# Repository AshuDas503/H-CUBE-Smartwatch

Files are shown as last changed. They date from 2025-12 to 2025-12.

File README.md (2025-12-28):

# H-CUBE-Smartwatch
A custom retro-style smartwatch powered by ESP32-S3 and HCMS-2971 LED display. Open-source hardware and firmware.

# H-CUBE: Retro-Style ESP32-S3 Smartwatch






**H-CUBE** ("Hardware Cube") is a fully custom, open-source smartwatch project that blends 80s retro aesthetics with modern IoT capabilities. Powered by the **ESP32-S3** and featuring a vintage **HCMS-2971** alphanumeric LED display, this wearable serves as a compact development platform for embedded systems, integrating GPS, motion sensing, and power management into a 3D-printed enclosure.

---

## 📸 Gallery

<!-- Upload images to an 'images' folder in your repo and uncomment the lines below -->
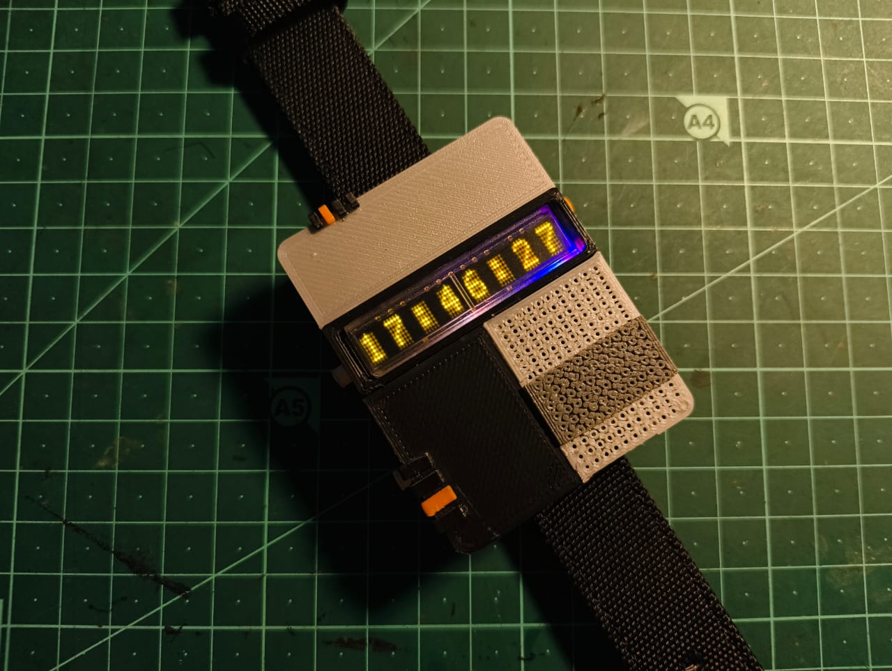
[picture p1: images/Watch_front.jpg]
H-CUBE Front View

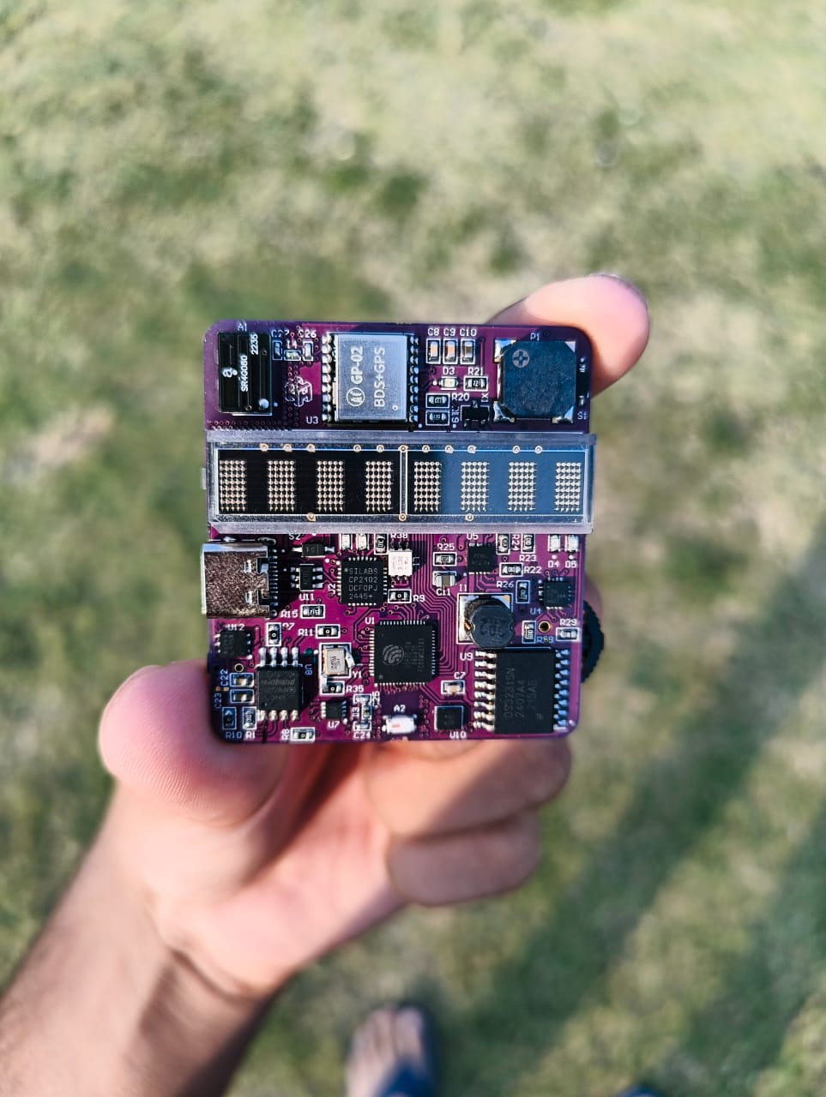
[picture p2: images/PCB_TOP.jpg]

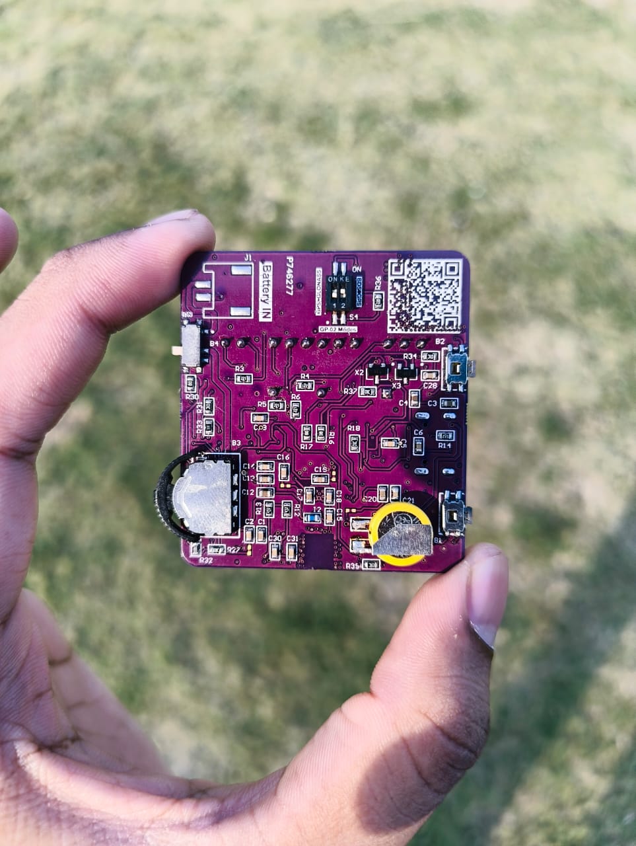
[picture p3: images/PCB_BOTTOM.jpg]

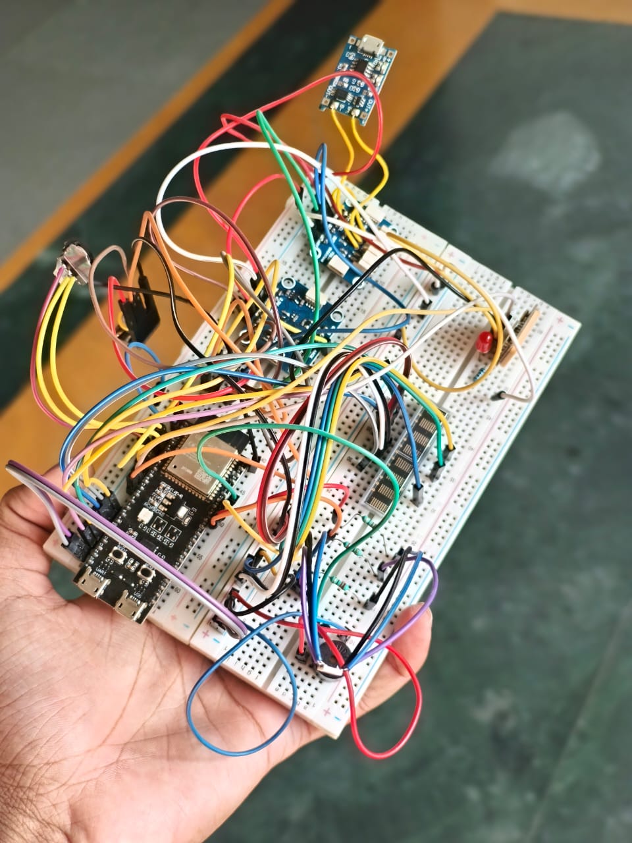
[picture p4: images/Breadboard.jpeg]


---

## 🚀 Features

### Hardware
*   **Core:** ESP32-S3 (Dual-core 240 MHz, WiFi + BLE 5.0).
*   **Display:** HCMS-2971 8-Character Yellow Alphanumeric LED (Vintage aesthetic, ~2000 nits brightness).
*   **Sensors:**
    *   **IMU:** BMI270 (6-axis accelerometer/gyroscope) for motion detection and wake-on-raise.
    *   **GPS:** GP-02 GNSS module for location tracking and time sync.
    *   **RTC:** DS3231 Precision Real-Time Clock for accurate timekeeping during sleep.
*   **Power:**
    *   **Charger:** BQ24075 with power path management.
    *   **Fuel Gauge:** MAX17048 for precise battery percentage monitoring.
    *   **Runtime:** 8-12 hours active use, with intelligent deep-sleep (10s timeout).
*   **User Interface:** 3-way navigation switch, RGB LED indicators, and Piezo Buzzer.

### Firmware & Software
*   **12 Operational Modes:** Time, Date, GPS Info, Temperature, Alarm, Stopwatch, Timer, RGB Control, Battery Status, Settings, etc.
*   **Connectivity:** Bluetooth SPP (Serial Port Profile) for phone pairing and WiFi for NTP time sync.
*   **OTA Updates:** Supports Over-The-Air firmware flashing.
*   **Power Saving:** Optimized sleep routines using the ESP32 ULP (Ultra Low Power) co-processor features.

---

## 🛠️ Tech Stack & Tools

*   **PCB Design:** Altium Designer (4-Layer Stackup, Impedance Controlled).
*   **CAD/Enclosure:** Autodesk Fusion 360 (Housing), KeyShot/Rhino (Rendering).
*   **Firmware:** C/C++ (Arduino IDE / PlatformIO).
*   **Fabrication:** 3D Printing (SLA/FDM for enclosure), Hot-plate Reflow (SMD Assembly).

---

## ⚡ Getting Started

### 1. Prerequisites
*   **Hardware:** H-CUBE PCB (assembled), LiPo Battery (3.7V), FTDI programmer (if not using USB-native boot).
*   **Software:** Arduino IDE (v2.0+) or PlatformIO.

### 2. Firmware Installation
1.  Clone this repository:
    ```
    git clone https://github.com/AshuDas503/H-CUBE.git
    ```
2.  Open the project in **Arduino IDE**.
3.  Install required libraries via Library Manager:
    *   `Adafruit_NeoPixel`
    *   `RTClib` (Adafruit)
    *   `SparkFun_BMI270_Arduino_Library`
    *   `TinyGPSPlus`
    *   *Note: Check `firmware/library_list.txt` for specific versions.*
4.  Select Board: **ESP32S3 Dev Module**.
    *   *USB CDC On Boot:* Enabled
    *   *Flash Size:* 8MB (or matches your specific IC)
5.  Connect the H-CUBE via USB and click **Upload**.

### 3. Assembly
*   Refer to the `Enclosure/README.md` for 3D printing settings (Layer height: 0.12mm recommended).
*   Wiring diagrams and pinout maps can be found in `Hardware/schematics/`.

---

## 🎮 Controls

*   **Center Click:** Wake / Enter Menu / Select.
*   **Up/Down:** Navigation / Value Adjustment.
*   **Long Press (Center):** Power Off / Sleep.

---

## 🤝 Contributing

Contributions are welcome!
1.  Fork the Project
2.  Create your Feature Branch (`git checkout -b feature/AmazingFeature`)
3.  Commit your Changes (`git commit -m 'Add some AmazingFeature'`)
4.  Push to the Branch (`git push origin feature/AmazingFeature`)
5.  Open a Pull Request

---

## 📜 License

This project is licensed under the MIT License - see the [LICENSE](LICENSE) file for details.

---

## 🔗 References & Links

*   **Instructables Guide:** [https://www.instructables.com/H-CUBE-a-Retro-Style-Smart-Watch-Powered-by-an-ESP/]
*   **Video Demo:** [https://www.youtube.com/watch?v=HaJIaakPBnE&t=3s]

---

*Created by **Ashutosh Dash**.*

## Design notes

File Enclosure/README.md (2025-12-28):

# 3D Printing Instructions

## Settings
*   **Material:** PLA or PETG
*   **Layer Height:** 0.12mm (for fine detail on the buttons)
*   **Infill:** 100% (for durability)
*   **Supports:** Required for the button cutouts.

## Assembly
1.  Sand the button slots slightly.
2.  Insert the 3D printed buttons.
3.  Place the PCB...

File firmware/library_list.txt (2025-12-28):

H-CUBE FIRMWARE - REQUIRED LIBRARIES
====================================

Library Name                          | Version   | Purpose
--------------------------------------|-----------|----------------------------
Adafruit_NeoPixel                     | 1.10.7    | RGB LED control
RTClib (Adafruit)                     | 2.1.1     | DS3231 Real-Time Clock
SparkFun_BMI270_Arduino_Library       | 1.0.8     | BMI270 IMU sensor
TinyGPSPlus                           | 1.0.3     | GP-02 GPS parsing
LedDisplay (Stoffregen)               | 0.4.1     | HCMS-2971 alphanumeric LED display
Preferences                           | N/A       | Built-in ESP32 (no install needed)
Wire                                  | N/A       | Built-in I2C library
SPI                                   | N/A       | Built-in SPI library
WiFi                                  | N/A       | Built-in WiFi (ESP32)
BluetoothSerial                       | N/A       | Built-in Bluetooth (ESP32)

INSTALLATION INSTRUCTIONS:
==========================

1. Open Arduino IDE
2. Go to: Sketch > Include Library > Manage Libraries
3. Search for each library name above
4. Install the version listed
5. Restart Arduino IDE

For GitHub Installation (LedDisplay):
If not available in Library Manager, install manually:
1. Download: https://github.com/PaulStoffregen/LedDisplay
2. Extract to: ~/Documents/Arduino/libraries/
3. Restart Arduino IDE

For PlatformIO users:
Add to platformio.ini:
lib_deps =
    adafruit/Adafruit NeoPixel @ 1.10.7
    adafruit/RTClib @ 2.1.1
    sparkfun/SparkFun BMI270 Arduino Library @ 1.0.8
    mikalhart/TinyGPSPlus @ 1.0.3
    https://github.com/PaulStoffregen/LedDisplay.git

NOTES:
======
- If a library version is marked as "Built-in", you don't need to install it.
- Always use the versions listed above for compatibility.
- If you get compilation errors, check that all libraries are installed.

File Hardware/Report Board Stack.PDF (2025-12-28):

# Board Stack Report

Stack Up | Layer Stack
Layer | Board Layer Stack | Name | Material | Thickness | Constant | Dk | Df | Coverlay expansion | Color | Frequency | Solid | GlassTransTemp | Manufacturer | MaterialDescription | Description | Process | Orientation | Copper Orientation | Weight | Constructions | Resin | Pullback distance
1 | | Top Overlay | | 0mm
2 | | Top Solder | SM-001 | 0.0254mm | 4 | 4 | 0.03 | 0mm | #FF008000 | 1GHz | 1% | 125°C | Altium Designer | Solder Mask | Solder Mask
3 | | Top Surface Finish | Nickel, Gold | 0.004mm | | | | | #FFFFC400 | | | | | | | ENIG
4 | | SIG L1 | CF-004 | 0.035mm | | | | | | | | | Altium Designer | Copper Foil | Copper Foil | ED | BodyUp | Above | 28.34952g
5 | | PP1-2116 | PP-017 | 0.105mm | 4.3 | 4.3 | 0.02 | | | 1GHz | | 180°C | Altium Designer | | | | | | | 2116 | 57%
6 | | SIG L2 | CF-004 | 0.035mm | | | | | | | | | Altium Designer | Copper Foil | Copper Foil | ED | None | Above | 28.34952g | | | 0.508mm
7 | | Core-FR4 | Core-039 | 1.2mm | 4.8 | 4.8 | 0.02 | | | 1GHz | | 180°C | Altium Designer | FR4 | | | | | | 4-7628 | 40%
8 | | SIG L3 | CF-004 | 0.035mm | | | | | | | | | Altium Designer | Copper Foil | Copper Foil | ED | None | Below | 28.34952g | | | 0.508mm
9 | | PP2-2116 | PP-017 | 0.105mm | 4.3 | 4.3 | 0.02 | | | 1GHz | | 180°C | Altium Designer | | | | | | | 2116 | 57%
10 | | SIG L4 | CF-004 | 0.035mm | | | | | | | | | Altium Designer | Copper Foil | Copper Foil | ED | BodyDown | Below | 28.34952g
11 | | Bottom Surface Finish | Nickel, Gold | 0.004mm | | | | | #FFFFC400 | | | | | | | ENIG
12 | | Bottom Solder | SM-001 | 0.0254mm | 4 | 4 | 0.03 | 0mm | #FF008000 | 1GHz | 1% | 125°C | Altium Designer | Solder Mask | Solder Mask
13 | | Bottom Overlay | | 0mm
| Height : 1.60881mm

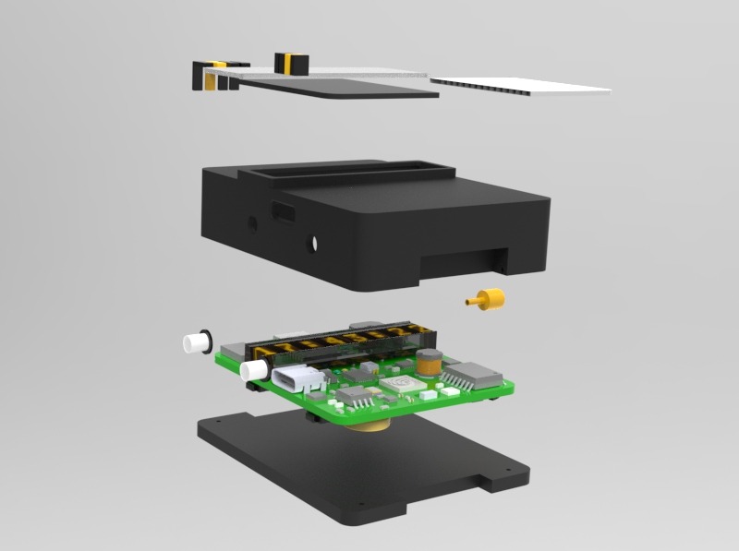
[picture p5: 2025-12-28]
images/Render 2.jpg

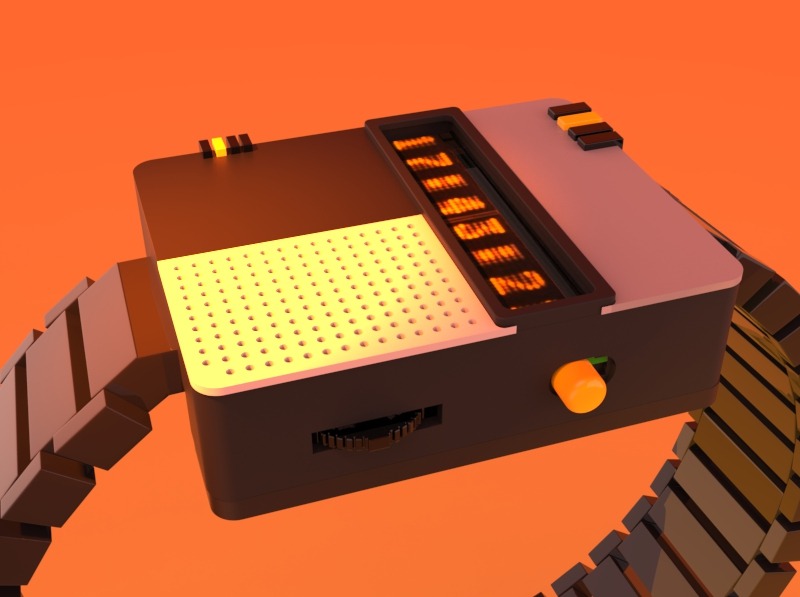
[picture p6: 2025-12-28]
images/Render 3.jpg

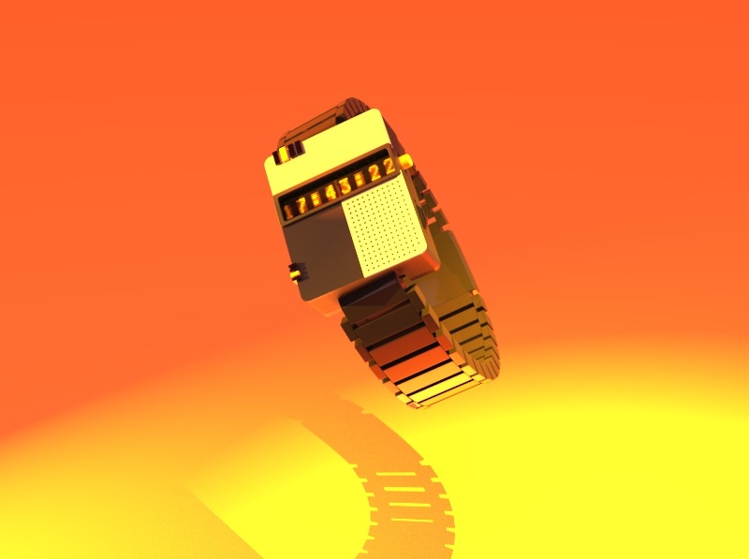
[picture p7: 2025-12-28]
images/Render 1.jpg

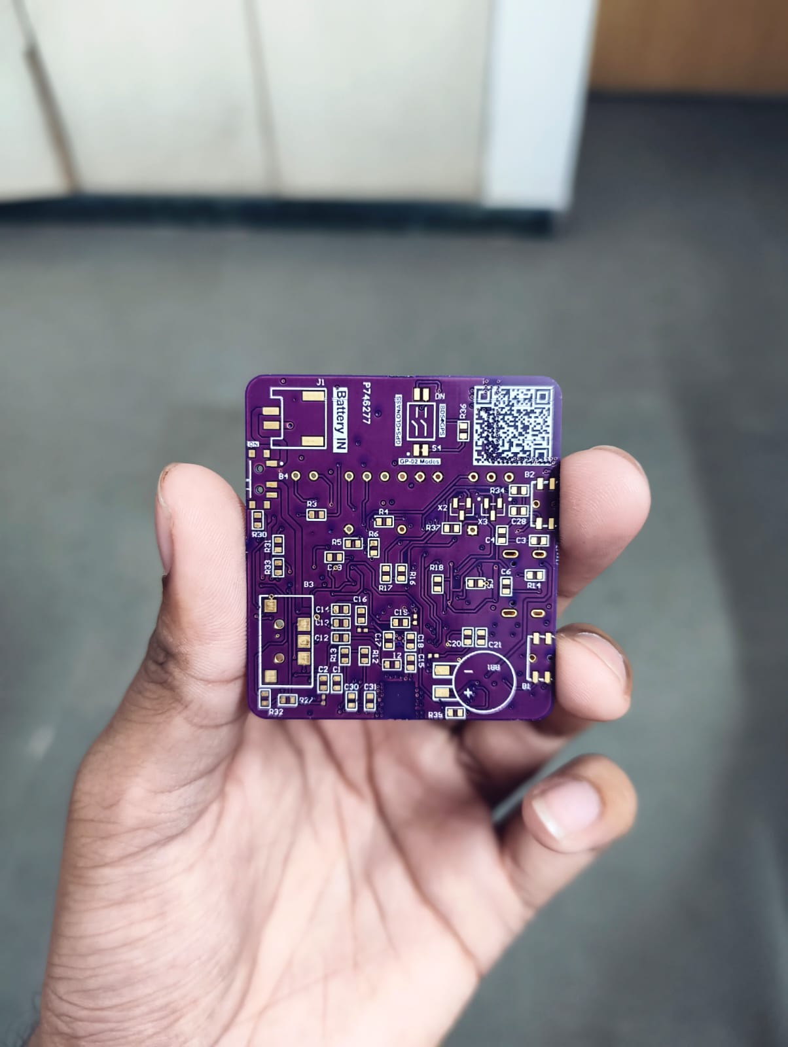
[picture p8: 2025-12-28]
images/PCB View1.jpg

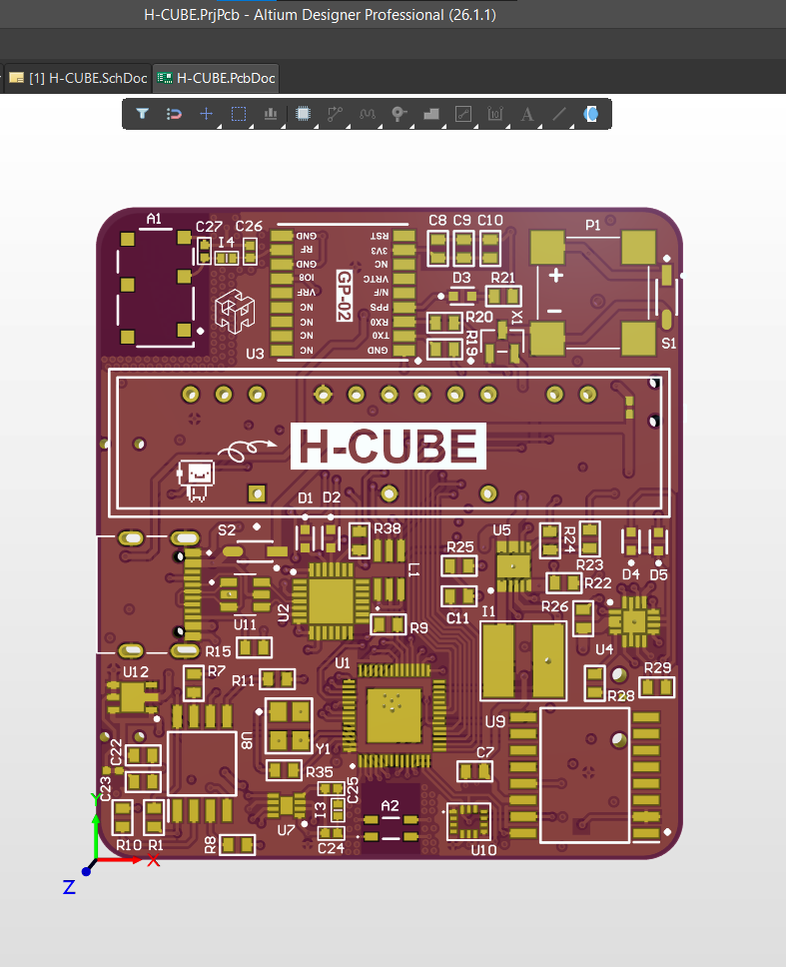
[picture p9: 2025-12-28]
images/3D TOP.png

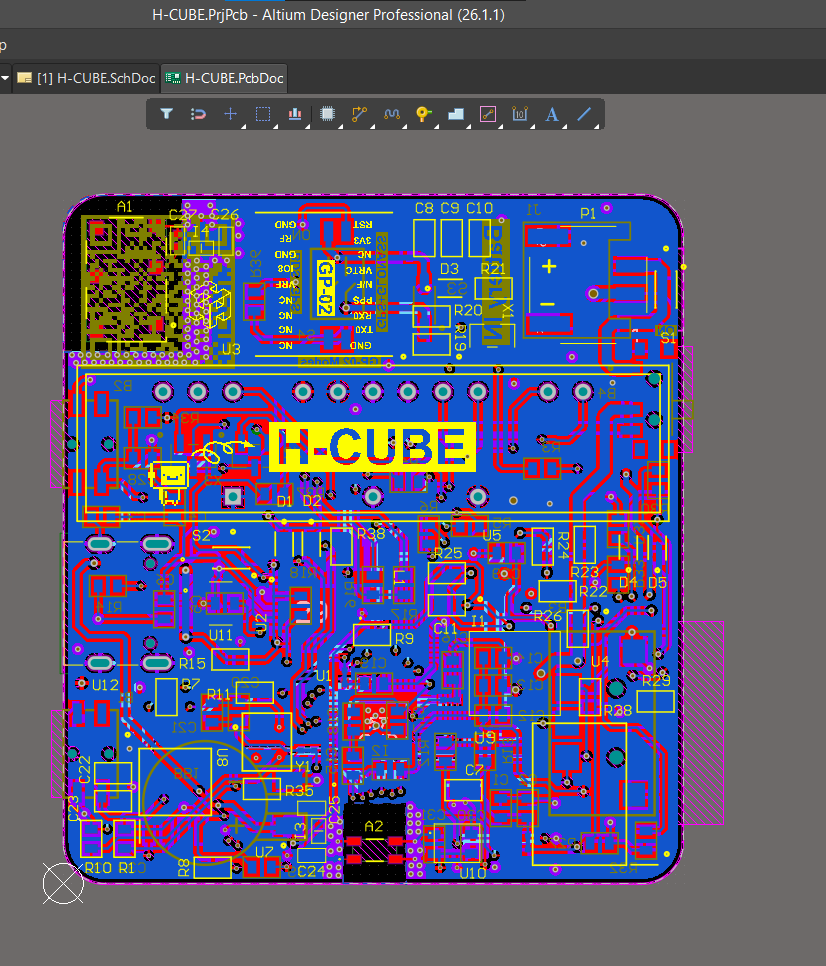
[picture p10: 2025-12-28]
images/Layer 4.png

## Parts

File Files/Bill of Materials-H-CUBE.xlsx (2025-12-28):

Line # | Name | Description | Designator | Quantity | Manufacturer 1 | Manufacturer Part Number 1 | Manufacturer Lifecycle 1 | Supplier 1 | Supplier Part Number 1 | Supplier Unit Price 1 | Supplier Subtotal 1
 | SR4G080 | GNSS Antenna chip type | A1 | 1
 | 2450AT18D0100001E | 2.4GHz Chip RF Antenna 2.4GHz ~ 2.5GHz 1.5dBi Solder Surface Mount | A2 | 1
 | BOOT |  | B1 | 1
 | RST |  | B2 | 1
 | LS-1305 | 3 way navigation switch Spring return, center push, Single knob can move CW/CCW/PUSH Specification:- Rating 10mA.5V DC Contact resitance 100MΩ max. Operating temperature range -30°C to +85°C Lifetime 100,000 Cycles min Operating force Lever portion 120±30gf / Push portion205±50gf Travel 3-direction-25°-0°~+25° / push portion 0.90±0.1mm | B3 | 1
 | CUS-12TB |  | B4 | 1
 | Battery |  | BB1 | 1
 | 1uf | 0603 ceramic capacitor | C1 | 1
 | 100nf | 0603 ceramic capacitor | C2, C14, C15, C16, C18, C19, C29, C30, C31 | 9
 | 1uF | 0603 ceramic capacitor | C3, C13, C17, C20, C22, C23 | 6
 | 10uF | 0603 ceramic capacitor | C4, C10, C12 | 3
 | 100nF | 0603 ceramic capacitor | C5, C6, C7, C8, C28 | 5
 | 820pF | 0603 ceramic capacitor | C9 | 1
 | 22uF | 0603 ceramic capacitor | C11 | 1
 | 10nF | 0603 ceramic capacitor | C21 | 1
 | 2.4pF | 0402 | C24 | 1
 | 2.7pF | 0402 | C25 | 1
 | 4.3pF | 0402 | C26 | 1
 | 3.6pF | 0402 | C27 | 1
 | 0603 G |  | D1 | 1
 | 0603 Y |  | D2 | 1
 | 0603 B |  | D3, D4 | 2
 | 0603 R |  | D5 | 1
 | HCMS-2971 | LED Displays & Accessories Yelow 585nm 1x8 Alphanumeric | H1 | 1
 | CD54-uH | Fixed Inductors SMD Power Inductor Unshielded | I1 | 1
 | 2nH | RF Inductors - SMD WE-KI 0603 2nH 700mA 80mOhms 0.2nH AEC-Q200 | I2 | 1
 | 2.4nH |  | I3 | 1
 | 5.1nH |  | I4 | 1
 | JST 2MM 2 |  | J1 | 1
 | ASMT-YTD2-0BB02 |  | L1 | 1
 | NT |  | NT1, NT2, NT3, NT4, NT5, NT6, NT7 | 7
 | MLT-8530 | PCB Mount type, SMD, External Drive, Magnetic 2700Hz 80dB Size Square 8.5x8.5x3mm, Low Profile, Sound output on side. | P1 | 1
 | 100k |  | R1, R22, R23, R26 | 4
 | 220R |  | R3, R4, R5, R6, R21 | 5
 | 0R |  | R7, R8, R9, R10, R11, R35 | 6
 | 4K7 |  | R12, R13 | 2
 | 5K1 |  | R14, R15 | 2
 | 1K |  | R16, R17, R29, R30 | 4
 | 10k |  | R18, R37 | 2
 | 22R |  | R19, R20, R36 | 3
 | 750K |  | R24, R25 | 2
 | 10K |  | R27, R34, R38, R39 | 4
 | 100K |  | R28 | 1
 | 20K |  | R31 | 1
 | 1.18K |  | R32 | 1
 | 1.13K |  | R33 | 1
 | B5819W Diode | 1N5819 B5819W 1N5819W SOD123 (1206) 1A 40V Schottky Diode | S1, S2 | 2
 | 97R02ST |  | S4 | 1
 | ESP32-S3 |  | U1 | 1
 | CP2102 | USB-to-UART 1-CH 640byte FIFO 3.3V Automotive 28-Pin QFN EP Tube | U2 | 1
 | GP-02 GNSS | GP-02 is a high-performance BDS/GNSS multi-mode satellite navigation receiver SOCmodule, which integrates RF front-end, digital baseband processor, 32-bit RISCCPU, power management and active antenna detection and protection functions. Support avariety of satellite navigation systems, including China's Beidou satellite navigationsystem BDS, the United States' GPS, and Russia's GLONASS, which canrealizemulti-system joint positioning | U3 | 1
 | BQ24075RGTR | Battery Management Li-Ion Batt Chrgr & Pwr-Path Mgmt IC A 595-BQ24075RGTT | U4 | 1
 | PAM2401YPADJ | Switching Voltage Regulators 1.0MHz Step-Up Conv 0.9 to 4.75V 3A 1KHz | U5 | 1
 | MAX17048G+T10 | Battery Management 3 A 1-Cell/2-Cell Fuel Gauge with ModelGauge | U7 | 1
 | W25Q128FVSIG |  | U8 | 1
 | DS3231 |  | U9 | 1
 | BMI270 | The BMI270 is an ultra-low power smart IMU optimized for wearable and hearable applications | U10 | 1
 | USBLC6-2SC6 |  | U11 | 1
 | LP38690SDX-3.3/NOPB | LDO Voltage Regulators 1-A 10-V low-dropo ut voltage regulator A 926-LP38690SD33NOPB | U12 | 1
 | USB Type-C |  | USB1 | 1
 | BC847 NPN | Transistors Bipolar NPN 45V 100MA 100MHZ SOT23, SMD Eqv of BC547 | X1 | 1
 | S8050 | igh Current General Purpose NPN transistor Eqv MBT8050LT1G, BC817 | X2, X3 | 2
 | YSX321SL_40MHz |  | Y1 | 1

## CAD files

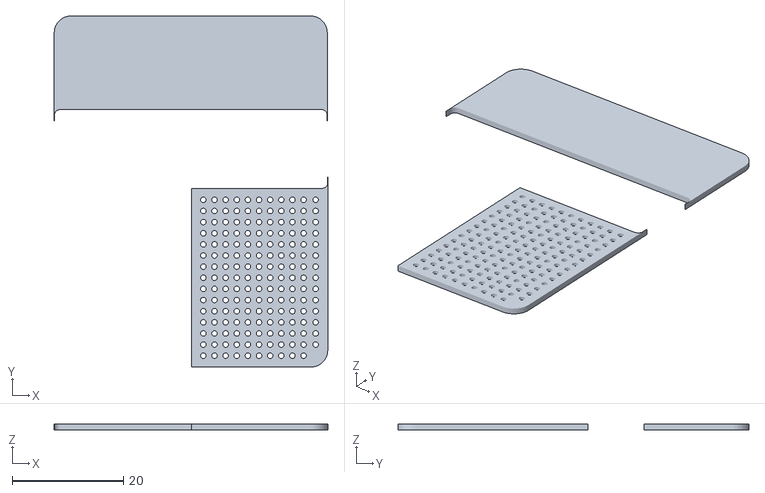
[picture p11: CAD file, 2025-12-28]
Enclosure/silver parts.stl
49.1 x 63.0 x 1.00

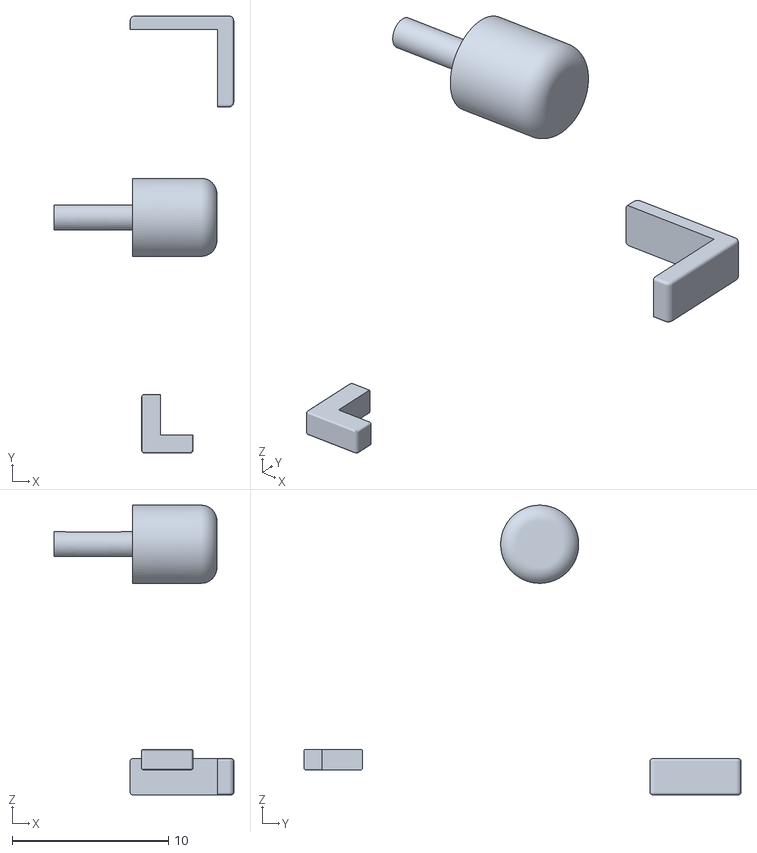
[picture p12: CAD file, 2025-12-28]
Enclosure/orange parts.stl
11.5 x 28.0 x 18.5

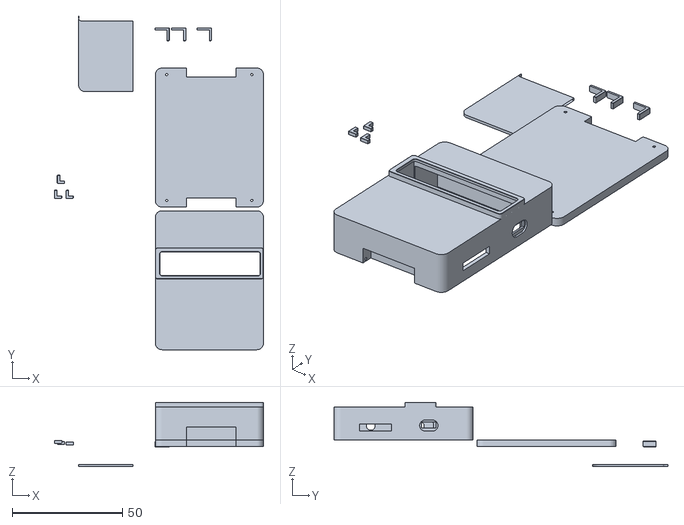
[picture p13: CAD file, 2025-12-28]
Enclosure/Black parts.stl
94.7 x 151.2 x 29.0

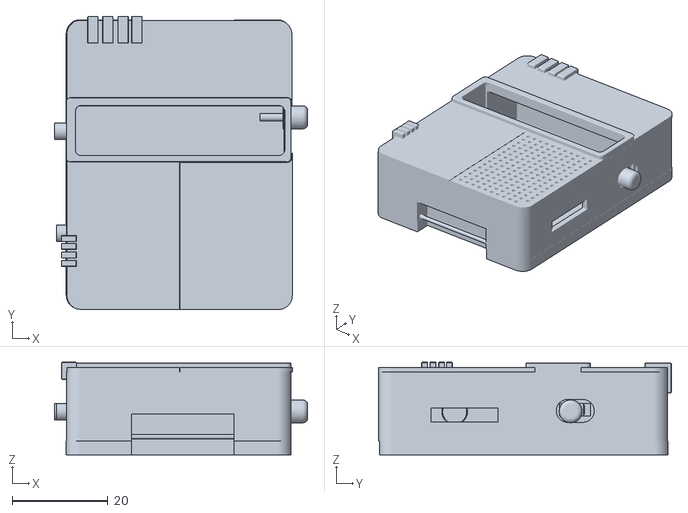
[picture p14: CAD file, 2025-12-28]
Enclosure/H-CUBE.stl
52.9 x 61.2 x 19.4

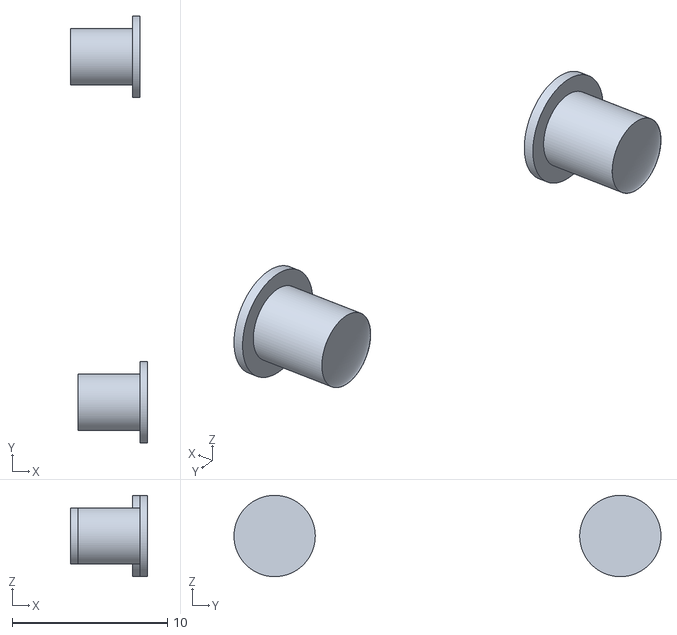
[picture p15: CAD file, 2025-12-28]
Enclosure/White parts.stl
4.98 x 27.5 x 5.24

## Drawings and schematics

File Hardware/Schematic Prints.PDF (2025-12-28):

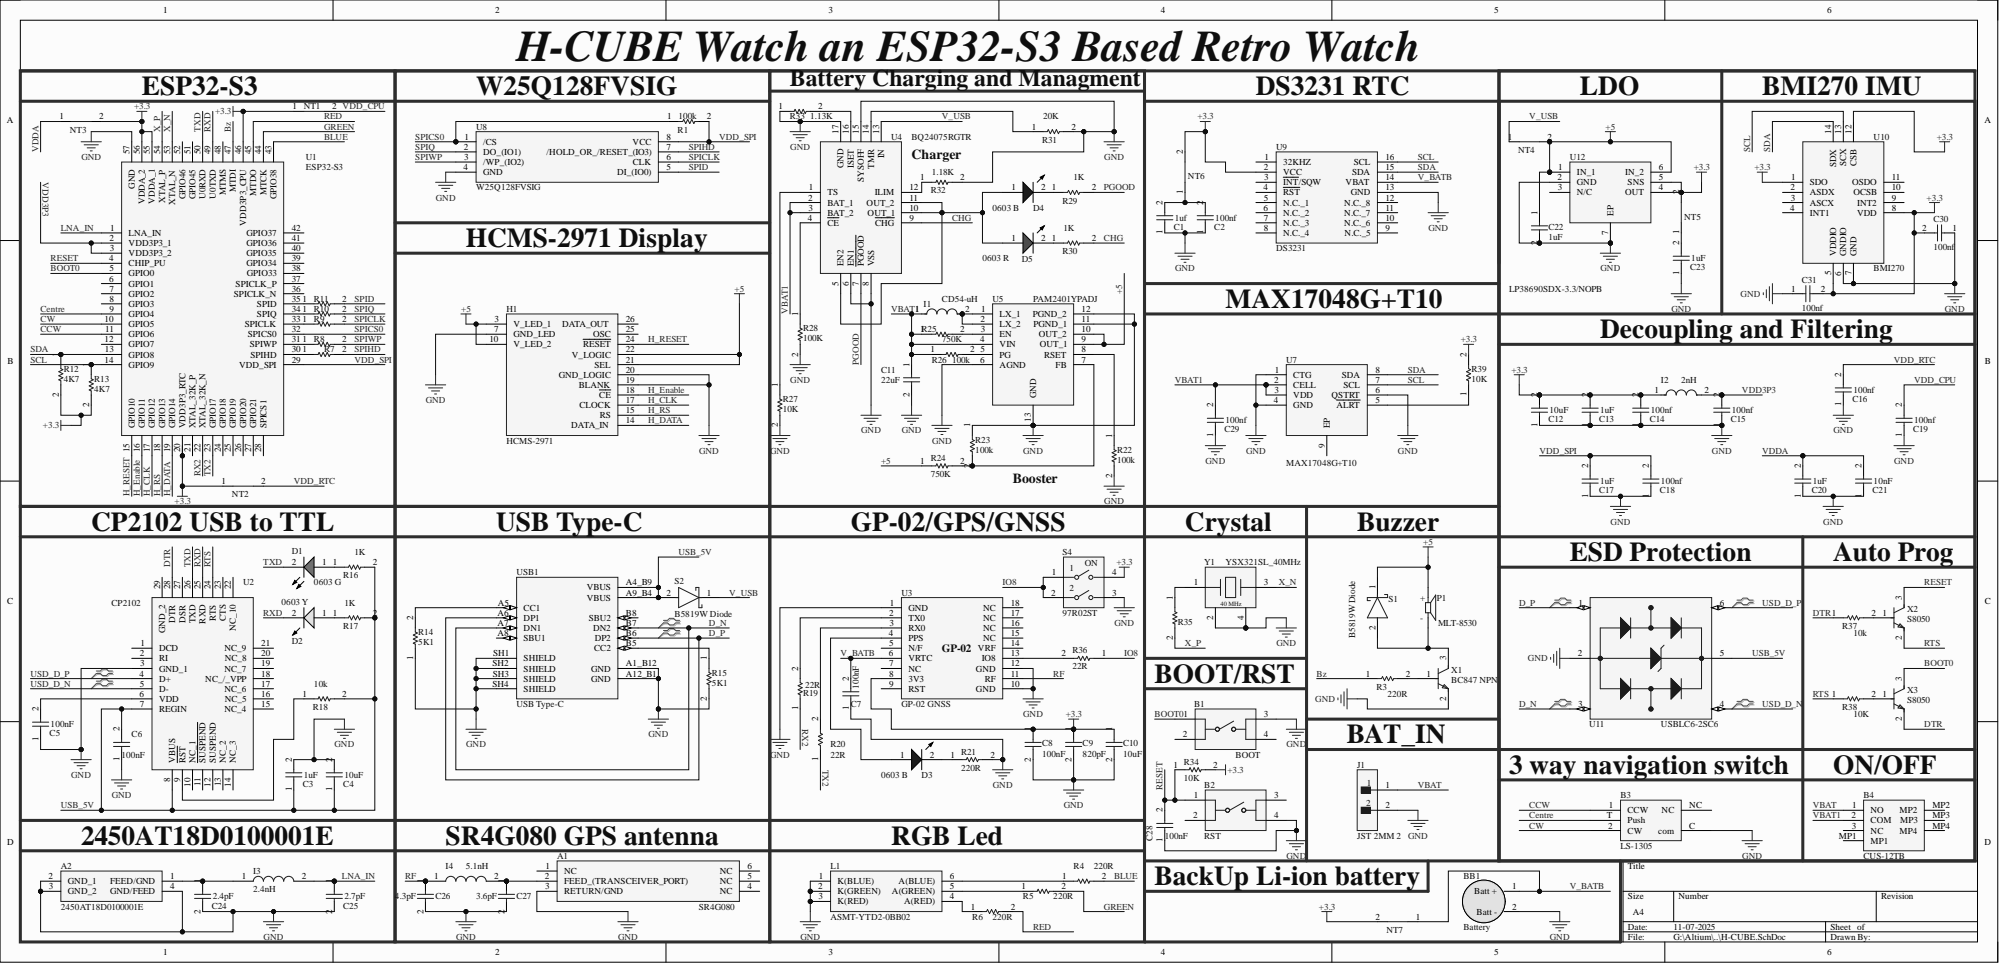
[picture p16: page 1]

H-CUBE Watch an ESP32-S3 Based Retro Watch
W25Q128FVSIG

Battery Charging and Managment

GND 7 VDD 8 INT2 9 OCSB 10 OSDO 11

CP2102 USB to TTL | USB Type-C | GP-02/GPS/GNSS | Crystal | Buzzer | GND

USB_5V | S4 | Y1 YSX321SL_40MHz | +5 | ESD Protection | Auto Prog

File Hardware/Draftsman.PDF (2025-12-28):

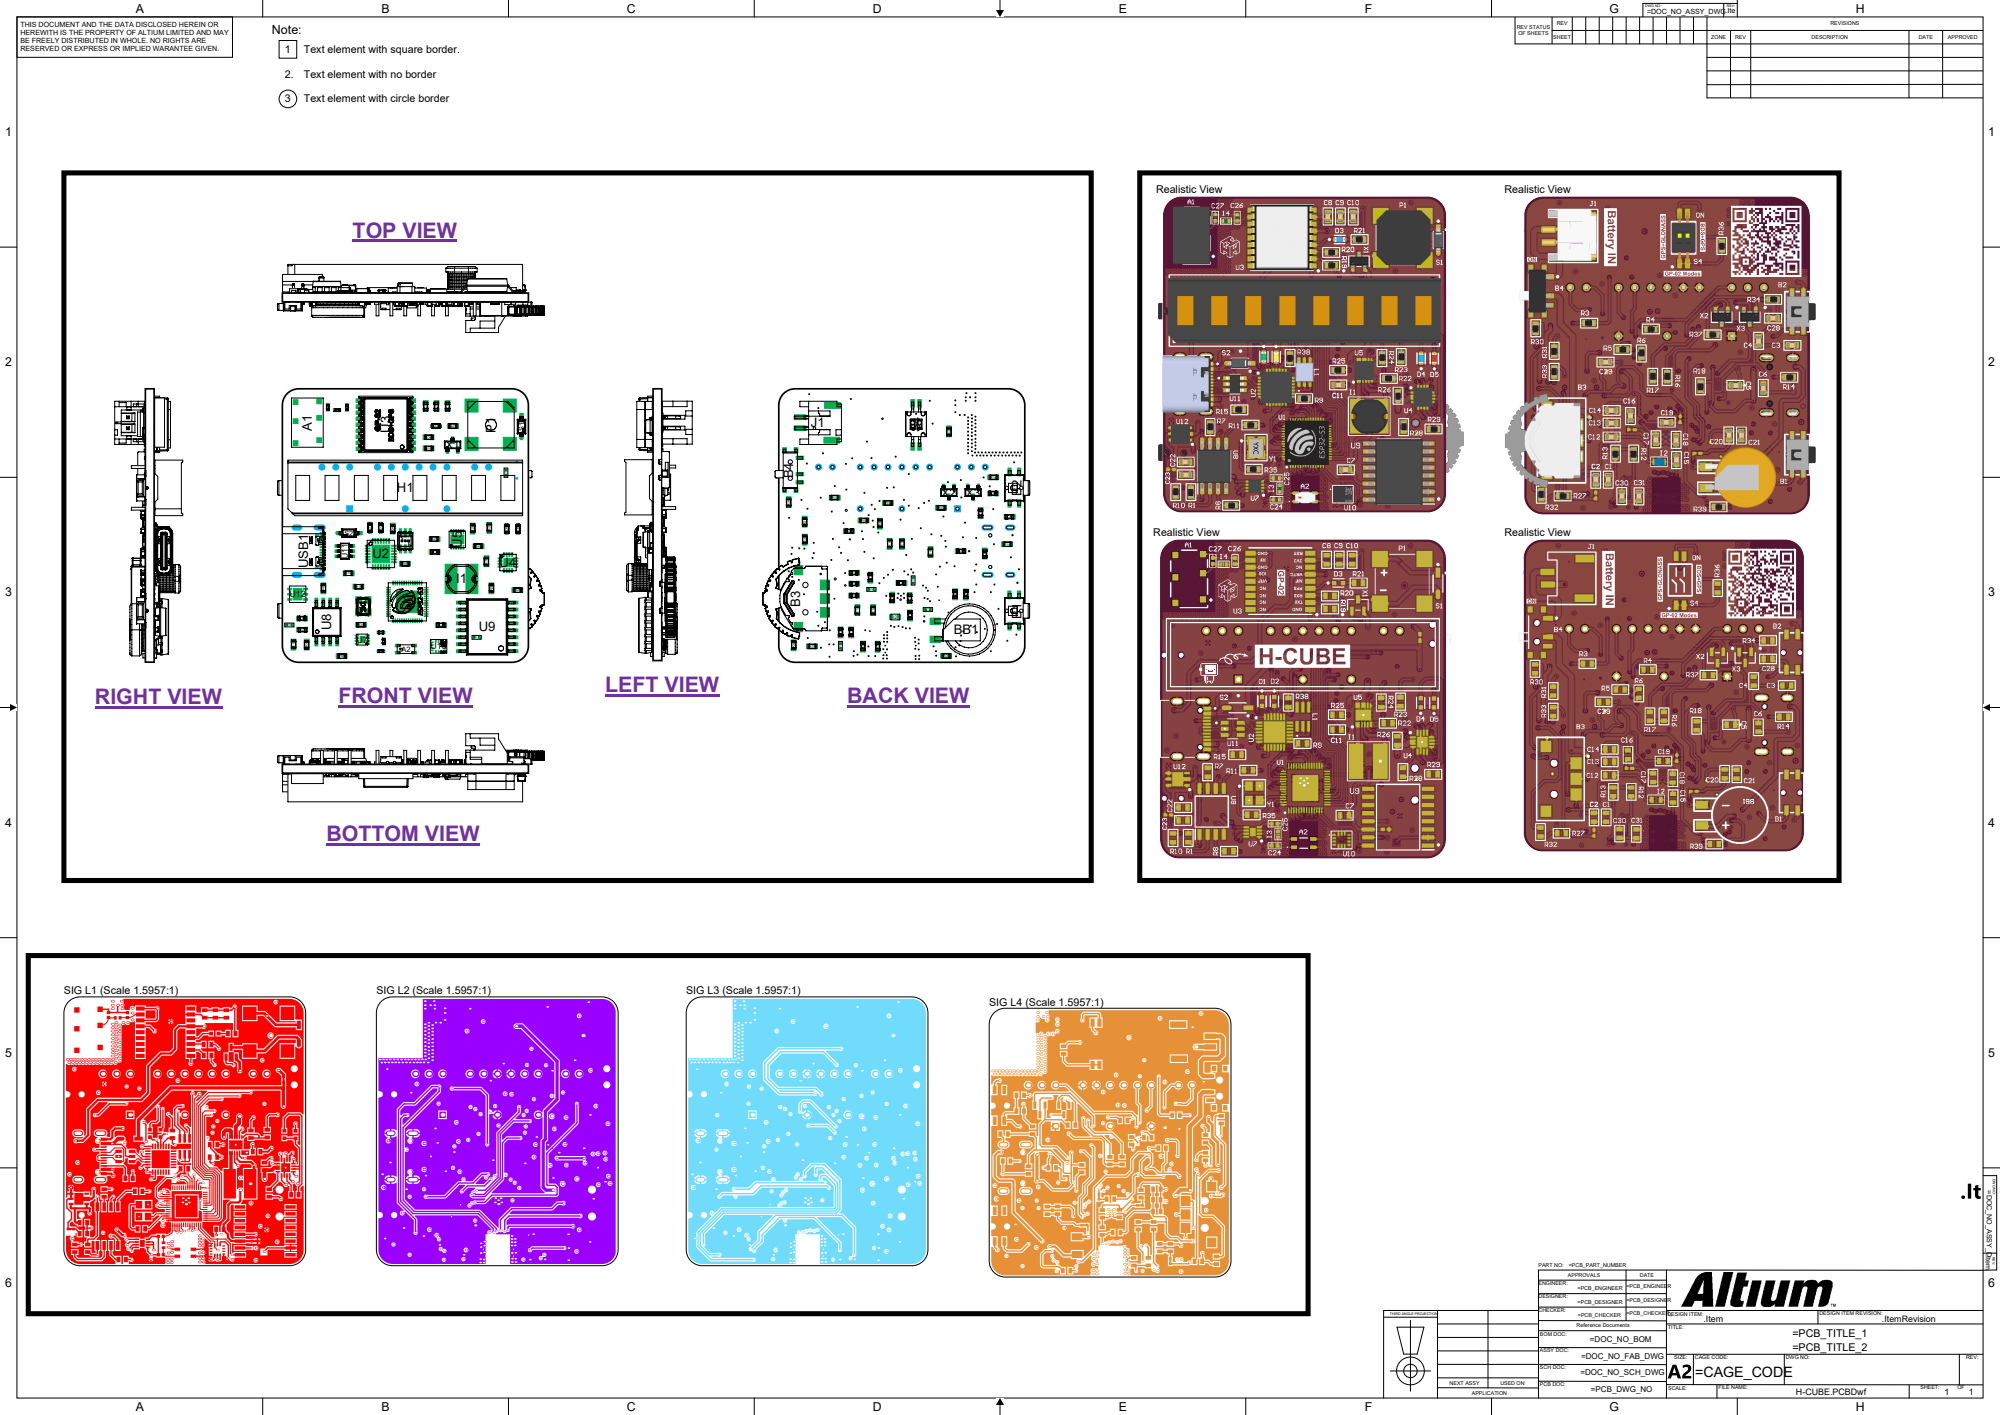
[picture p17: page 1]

THIS DOCUMENT AND THE DATA DISCLOSED HEREIN OR
HEREWITH IS THE PROPERTY OF ALTIUM LIMITED AND MAY
BE FREELY DISTRIBUTED IN WHOLE. NO RIGHTS ARE
RESERVED OR EXPRESS OR IMPLIED WARANTEE GIVEN.

Note:
1 Text element with square border.

2. Text element with no border

3 Text element with circle border

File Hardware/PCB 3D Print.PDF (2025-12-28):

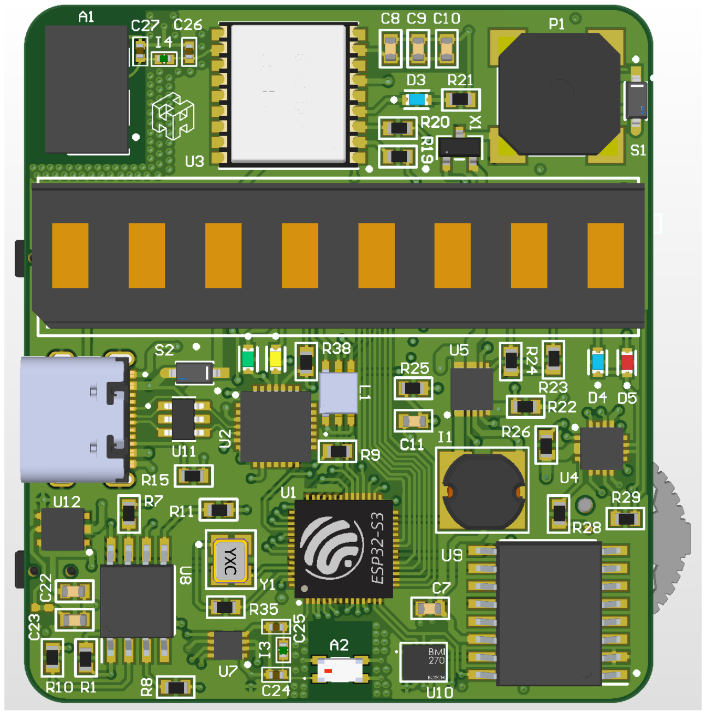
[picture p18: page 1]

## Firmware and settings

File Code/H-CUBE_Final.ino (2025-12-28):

#include <Wire.h>
#include <RTClib.h>
#include <LedDisplay.h>
#include "SparkFun_BMI270_Arduino_Library.h"
#include <TinyGPSPlus.h>
#include <Preferences.h>
#include <SparkFun_MAX1704x_Fuel_Gauge_Arduino_Library.h>

// -------------------------
// HCMS-2971 connections
// -------------------------
#define dataPin        14
#define registerSelect 13
#define clockPin       12
#define enable         11
#define reset          10
#define displayLength  8
LedDisplay myDisplay = LedDisplay(dataPin, registerSelect, clockPin, enable, reset, displayLength);

// -------------------------
// RTC & IMU setup
// -------------------------
RTC_DS3231 rtc;
BMI270 imu;
uint8_t bmiAddress = BMI2_I2C_SEC_ADDR; // 0x69

// -------------------------
// GPS setup
// -------------------------
TinyGPSPlus gps;
#define GPS_RX 16
#define GPS_TX 17
#define gpsSerial Serial2

// -------------------------
// RGB LED (PWM outputs)
// -------------------------
#define LED_R 38
#define LED_G 39
#define LED_B 40
#define LEDC_FREQ 1000
#define LEDC_RES 8

int rgbR = 255, rgbG = 70, rgbB = 0; // default amber

// -------------------------
// Buzzer (Alarm output)
// -------------------------
#define BUZZER_PIN 41

// -------------------------
// Buttons
// -------------------------
#define BTN_UP     5
#define BTN_DOWN   6
#define BTN_CENTER 4

// -------------------------
// Preferences (Flash storage)
// -------------------------
Preferences prefs;

// -------------------------
// Battery Fuel Gauge (MAX17048)
// -------------------------
SFE_MAX1704X lipo(MAX1704X_MAX17048);
float lastVoltage = 0;
float lastSOC = 0;
bool isCharging = false;
unsigned long lastBatteryCheck = 0;
bool showBatteryMode = false;
bool chargingDisplayActive = false;
unsigned long lastChargeCheck = 0;

// -------------------------
// State variables
// -------------------------
bool inMenu = false;
bool brightnessSettingMode = false;
bool showDateMode = false;
bool showStepsMode = false;
bool showGPSMode = false;
bool showTempMode = false;
bool rgbMode = false;
bool stopwatchMode = false;
bool alarmMode = false;
bool alarmActive = false;
bool justEnteredMenu = false;

int menuIndex = 0;
const int totalMenus = 11; // includes Battery + Timer

// Timing
unsigned long lastInteraction = 0;
unsigned long pressStartTime = 0;
bool longPressTriggered = false;

const unsigned long holdTime = 5000;
const unsigned long sleepTimeout = 10000;

// Stopwatch
unsigned long stopwatchStart = 0;
unsigned long stopwatchElapsed = 0;
bool stopwatchRunning = false;

// Alarm
int alarmHour = 7;
int alarmMinute = 0;
bool alarmSet = false;
int alarmField = 0;
unsigned long lastBeep = 0;
bool beepState = false;

// Brightness
int currentBrightness = 15;

// Splash flag
bool showSplashNext = false;

// -------------------------
// Timer variables (NEW)
// -------------------------
bool timerMode = false;
bool timerRunning = false;
bool timerFinished = false;
unsigned long timerStartMillis = 0;
unsigned long timerDurationMillis = 0; // total countdown in ms (remaining when paused)
int timerSetMinutes = 0;
int timerSetSeconds = 30;
int timerSelectField = 0; // 0 = minutes, 1 = seconds
unsigned long timerLastUpdate = 0;

// -------------------------
// Helper
// -------------------------
void printDisplay(const char* str) {
  char buf[9];
  snprintf(buf, 9, "%-8s", str);
  myDisplay.home();
  myDisplay.print(buf);
}

void timerSavePrefs() {
  prefs.begin("watchprefs", false);
  prefs.putInt("timerMin", timerSetMinutes);
  prefs.putInt("timerSec", timerSetSeconds);
  prefs.end();
}

// -------------------------
// Setup
// -------------------------
void setup() {
  Serial.begin(115200);
  Wire.begin(8, 9);

  pinMode(BUZZER_PIN, OUTPUT);
  digitalWrite(BUZZER_PIN, LOW);

  pinMode(BTN_UP, INPUT_PULLUP);
  pinMode(BTN_DOWN, INPUT_PULLUP);
  pinMode(BTN_CENTER, INPUT_PULLUP);

  if (!rtc.begin()) {
    Serial.println("Couldn't find RTC!");
    while (1);
  }

  //rtc.adjust(DateTime(F(__DATE__), F(__TIME__)));
 
  myDisplay.begin();
  myDisplay.setBrightness(currentBrightness);
  myDisplay.clear();

  while (imu.beginI2C(bmiAddress) != BMI2_OK) {
    Serial.println("BMI270 not connected!");
    delay(1000);
  }
  imu.enableFeature(BMI2_STEP_COUNTER);

  gpsSerial.begin(9600, SERIAL_8N1, GPS_RX, GPS_TX);

  // --- Battery gauge init ---
  if (lipo.begin()) {
    lipo.quickStart();
    lastVoltage = lipo.getVoltage();
    lastSOC = lipo.getSOC();
    lastBatteryCheck = millis();
    Serial.println("MAX17048 OK");
  } else {
    Serial.println("MAX17048 not detected!");
  }

  ledcAttach(LED_R, LEDC_FREQ, LEDC_RES);
  ledcAttach(LED_G, LEDC_FREQ, LEDC_RES);
  ledcAttach(LED_B, LEDC_FREQ, LEDC_RES);

  prefs.begin("watchprefs", false);
  rgbR = prefs.getInt("rgbR", 255);
  rgbG = prefs.getInt("rgbG", 70);
  rgbB = prefs.getInt("rgbB", 0);
  alarmHour = prefs.getInt("alarmH", 7);
  alarmMinute = prefs.getInt("alarmM", 0);
  alarmSet = prefs.getBool("alarmOn", false);
  // load timer prefs
  timerSetMinutes = prefs.getInt("timerMin", 0);
  timerSetSeconds = prefs.getInt("timerSec", 30);
  prefs.end();

  timerDurationMillis = (unsigned long)timerSetMinutes * 60000UL + (unsigned long)timerSetSeconds * 1000UL;

  ledcWrite(LED_R, rgbR);
  ledcWrite(LED_G, rgbG);
  ledcWrite(LED_B, rgbB);

  Serial.println("System Ready");
}

// -------------------------
// Loop
// -------------------------
void loop() {
  unsigned long now = millis();
  handleButtons(now);

  while (gpsSerial.available() > 0)
    gps.encode(gpsSerial.read());

  // Alarm trigger
  if (alarmSet && !alarmActive) {
    DateTime nowt = rtc.now();
    if (nowt.hour() == alarmHour && nowt.minute() == alarmMinute && nowt.second() == 0) {
      alarmActive = true;
      lastBeep = millis();
    }
  }
  if (alarmActive) handleAlarmBeep();

// Timer finish buzzer handling (if timer finished and still in timerMode)
if (timerFinished) {
  int notes[] = {523, 587, 659, 698, 784, 880, 988, 1047};
  int count = sizeof(notes) / sizeof(notes[0]);
  bool stoppedByButton = false;

  for (int i = 0; i < count; i++) {
    tone(BUZZER_PIN, notes[i], 500);
    delay(650);
    noTone(BUZZER_PIN);

    // If user presses center, stop melody and consume the press
    if (digitalRead(BTN_CENTER) == LOW) {
      noTone(BUZZER_PIN);
      timerFinished = false;
      timerRunning = false;
      timerMode = false;           // <-- important: exit timer mode so it won't restart
      digitalWrite(BUZZER_PIN, LOW);
      myDisplay.clear();
      lastInteraction = millis();  // keep UI awake briefly
      stoppedByButton = true;
      // small debounce delay to avoid immediate re-detection by button polling
      delay(120);
      break;
    }
  }

  // If melody ended without button, still keep timerMode=false so user must re-enter timer menu
  if (!stoppedByButton) {
    timerMode = false;           // require user to explicitly re-enter timer to restart
    lastInteraction = millis();
  }

  printDisplay("00:00:00");
}


  // Modes
  if (alarmMode) { handleAlarmMode(); return; }
  if (rgbMode) { handleRGBMode(); return; }
  if (stopwatchMode) { showStopwatch(); return; }
  if (timerMode) { showTimer(); return; }   // Timer display & logic
  if (showBatteryMode) { showBattery(); return; }

  if (showTempMode) {
    static unsigned long lastTempUpdate = 0;
    if (millis() - lastTempUpdate > 1000) {
      showTemp();
      lastTempUpdate = millis();
    }
    if (digitalRead(BTN_CENTER) == LOW) {
      delay(150);
      showTempMode = false;
      myDisplay.clear();
    }
    return;
  }

  if (showDateMode) { showDate(); if (now - lastInteraction > 5000) { showDateMode = false; myDisplay.clear(); } return; }
  if (showStepsMode) { showSteps(); if (now - lastInteraction > 5000) { showStepsMode = false; myDisplay.clear(); } return; }
  if (showGPSMode) { showGPS(); if (now - lastInteraction > 5000) { showGPSMode = false; myDisplay.clear(); } return; }

  if (!inMenu && !brightnessSettingMode) {
    if (millis() - lastInteraction < sleepTimeout) showTime();
    else myDisplay.clear();
  } else showMenu();
}

// -------------------------
// Displays
// -------------------------
void showTime() {
  if (showSplashNext) {
    myDisplay.clear();
    delay(50);
    myDisplay.home();
    myDisplay.print(" H-CUBE ");
    delay(1200);
    myDisplay.clear();
    showSplashNext = false;
  }

  DateTime now = rtc.now();
  char buffer[9];
  snprintf(buffer, 9, "%02d:%02d:%02d", now.hour(), now.minute(), now.second());
  printDisplay(buffer);
}
void showDate() {
  DateTime now = rtc.now();
  char buffer[9];

  // Step 1: Show Date
  snprintf(buffer, 9, "%02d/%02d/%02d", now.day(), now.month(), now.year() % 100);
  printDisplay(buffer);
  delay(2000);

  // Step 2: Show Day
  const char* daysOfWeek[] = {"SUN", "MON", "TUE", "WED", "THU", "FRI", "SAT"};
  int dayIndex = now.dayOfTheWeek(); // from RTClib
  snprintf(buffer, 9, "%-8s", daysOfWeek[dayIndex]);
  printDisplay(buffer);
  delay(2000);

  // Step 3: Clear & exit
  showDateMode = false;
  myDisplay.clear();
}

void showSteps() {
  uint32_t stepCount = 0;
  imu.getStepCount(&stepCount);
  char buffer[9];
  snprintf(buffer, 9, "%8lu", stepCount);
  printDisplay(buffer);
}
void showTemp() {
  float tempC = rtc.getTemperature() - 1.0;
  char buf[9];
  snprintf(buf, 9, "TMP:%02.1fC", tempC);
  printDisplay(buf);
}
void showGPS() {
  if (gps.location.isValid()) {
    char latStr[9], lonStr[9];
    snprintf(latStr, 9, "LT:%05.2f", gps.location.lat());
    snprintf(lonStr, 9, "LO:%05.2f", gps.location.lng());
    printDisplay(latStr);
    delay(2000);
    printDisplay(lonStr);
    delay(2000);
  } else {
    printDisplay("NO GPS");
    delay(2000);
  }
  showGPSMode = false;
}

// -------------------------
// Timer display & logic
// -------------------------
void showTimer() {
  unsigned long now = millis();

  // If finished -> show 00:00 (handled in loop buzzer)
  if (timerFinished) {
    printDisplay("00:00:00");
    return;
  }

  if (!timerRunning) {
    // Setting mode display: show "SETMM:SS", selected field blinks OFF
    static unsigned long blinkT = 0;
    bool blinkOn = ((now / 400) & 1) == 0; // blink 400ms

    char buf[9];
    int displayMin = timerSetMinutes;
    int displaySec = timerSetSeconds;

    if (timerSelectField == 0 && !blinkOn) displayMin = -1; // use -1 to indicate blank
    if (timerSelectField == 1 && !blinkOn) displaySec = -1;

    if (displayMin == -1) {
      // blank minutes during blink OFF
      snprintf(buf, 9, "SET  :%02d", displaySec);
    } else if (displaySec == -1) {
      snprintf(buf, 9, "SET%02d:  ", displayMin);
    } else {
      snprintf(buf, 9, "SET%02d:%02d", displayMin, displaySec);
    }
    printDisplay(buf);
  } else {
    // timer running -> show remaining time (update fast enough)
    unsigned long elapsed = millis() - timerStartMillis;
    if (elapsed >= timerDurationMillis) {
      // finished
      timerRunning = false;
      timerFinished = true;
      printDisplay("00:00:00");
      return;
    } else {
      unsigned long remaining = timerDurationMillis - elapsed;
      unsigned int mins = (remaining / 60000UL) % 60;
      unsigned int secs = (remaining / 1000UL) % 60;
      unsigned int hund = (remaining % 1000UL) / 10;
      char buf[9];
      snprintf(buf, 9, "%02d:%02d:%02d", mins, secs, hund);
      printDisplay(buf);
    }
  }
}

// -------------------------
// Stopwatch
// -------------------------
void showStopwatch() {
  static unsigned long lastUpdate = 0;
  unsigned long now = millis();
  if (now - lastUpdate >= 100) {
    unsigned long elapsed = stopwatchRunning ? millis() - stopwatchStart + stopwatchElapsed : stopwatchElapsed;
    unsigned int minutes = (elapsed / 60000) % 60;
    unsigned int seconds = (elapsed / 1000) % 60;
    unsigned int hundredths = (elapsed % 1000) / 10;
    char buf[9];
    snprintf(buf, 9, "%02d:%02d:%02d", minutes, seconds, hundredths);
    printDisplay(buf);
    lastUpdate = now;
  }
  static bool centerPrev = HIGH;
  bool center = digitalRead(BTN_CENTER);
  if (centerPrev == HIGH && center == LOW) {
    unsigned long pressStart = millis();
    while (digitalRead(BTN_CENTER) == LOW) delay(10);
    unsigned long pressDuration = millis() - pressStart;
    if (pressDuration < 800) {
      if (!stopwatchRunning) { stopwatchRunning = true; stopwatchStart = millis(); }
      else { stopwatchRunning = false; stopwatchElapsed += millis() - stopwatchStart; }
    } else {
      stopwatchRunning = false;
      stopwatchElapsed = 0;
      stopwatchMode = false;
      myDisplay.clear();
    }
  }
  centerPrev = center;
}

// -------------------------
//  Battery Menu
// -------------------------
void showBattery() {
  float voltage = lipo.getVoltage();
  float soc = lipo.getSOC();
  char buf[9];
  snprintf(buf, 9, "BAT:%.2f", voltage);
  printDisplay(buf);
  delay(2000);
  snprintf(buf, 9, "SOC:%02d%%", (int)soc);
  printDisplay(buf);
  delay(2000);
  showBatteryMode = false;
  myDisplay.clear();
}

// -------------------------
// RGB Mode
// -------------------------
void handleRGBMode() {
  static int colorIndex = 0;
  int *color = (colorIndex == 0 ? &rgbR : colorIndex == 1 ? &rgbG : &rgbB);
  const char *label = (colorIndex == 0 ? "RED" : colorIndex == 1 ? "GRN" : "BLU");
  static bool upPrev = HIGH, downPrev = HIGH, centerPrev = HIGH;
  static unsigned long lastChangeTime = 0;
  static unsigned long holdStartUp = 0, holdStartDown = 0;
  const unsigned long slowDelay = 150, fastDelay = 40;
  bool up = digitalRead(BTN_UP), down = digitalRead(BTN_DOWN), center = digitalRead(BTN_CENTER);
  unsigned long now = millis();
  if (up == LOW) {
    if (holdStartUp == 0) holdStartUp = now;
    unsigned long delayVal = map(constrain(now - holdStartUp, 0, 3000), 0, 3000, slowDelay, fastDelay);
    if (now - lastChangeTime > delayVal) { *color = min(255, *color + 1); lastChangeTime = now; }
  } else holdStartUp = 0;
  if (down == LOW) {
    if (holdStartDown == 0) holdStartDown = now;
    unsigned long delayVal = map(constrain(now - holdStartDown, 0, 3000), 0, 3000, slowDelay, fastDelay);
    if (now - lastChangeTime > delayVal) { *color = max(0, *color - 1); lastChangeTime = now; }
  } else holdStartDown = 0;
  ledcWrite(LED_R, rgbR);
  ledcWrite(LED_G, rgbG);
  ledcWrite(LED_B, rgbB);
  char buf[9]; snprintf(buf, 9, "%s:%03d", label, *color); printDisplay(buf);
  if (centerPrev == HIGH && center == LOW) {
    colorIndex++;
    if (colorIndex > 2) {
      prefs.begin("watchprefs", false);
      prefs.putInt("rgbR", rgbR);
      prefs.putInt("rgbG", rgbG);
      prefs.putInt("rgbB", rgbB);
      prefs.end();
      rgbMode = false;
      colorIndex = 0;
      myDisplay.clear();
      return;
    }
    delay(200);
  }
  upPrev = up; downPrev = down; centerPrev = center;
}

// -------------------------
// Alarm Logic
// -------------------------
void handleAlarmMode() {
  static bool upPrev = HIGH, downPrev = HIGH, centerPrev = HIGH;
  bool up = digitalRead(BTN_UP), down = digitalRead(BTN_DOWN), center = digitalRead(BTN_CENTER);
  if (upPrev == HIGH && up == LOW) {
    if (alarmField == 0) alarmHour = (alarmHour + 1) % 24;
    else alarmMinute = (alarmMinute + 1) % 60;
  }
  if (downPrev == HIGH && down == LOW) {
    if (alarmField == 0) alarmHour = (alarmHour + 23) % 24;
    else alarmMinute = (alarmMinute + 59) % 60;
  }
  char buf[9]; snprintf(buf, 9, "%02d:%02d", alarmHour, alarmMinute); printDisplay(buf);
  if (centerPrev == HIGH && center == LOW) {
    alarmField++;
    if (alarmField > 1) {
      alarmField = 0;
      alarmMode = false;
      alarmSet = true;
      prefs.begin("watchprefs", false);
      prefs.putInt("alarmH", alarmHour);
      prefs.putInt("alarmM", alarmMinute);
      prefs.putBool("alarmOn", true);
      prefs.end();
      myDisplay.clear();
    }
  }
  upPrev = up; downPrev = down; centerPrev = center;
}

void handleAlarmBeep() {
  // melody notes (example scale)
  int notes[] = {523, 587, 659, 698, 784, 880, 988, 1047};
  int count = sizeof(notes) / sizeof(notes[0]);

  for (int i = 0; i < count; i++) {
    tone(BUZZER_PIN, notes[i], 500);
    delay(650);
    noTone(BUZZER_PIN);

    // allow stopping alarm by button press
    if (digitalRead(BTN_UP) == LOW ||
        digitalRead(BTN_DOWN) == LOW ||
        digitalRead(BTN_CENTER) == LOW) {
      noTone(BUZZER_PIN);
      alarmActive = false;
      return;
    }
  }
}


// -------------------------
// Buttons + Menu (includes Timer handling)
// -------------------------
void handleButtons(unsigned long now) {
  // Timer mode override: handle timer-specific button logic first
  if (timerMode) {
    static bool upPrev = HIGH, downPrev = HIGH, centerPrev = HIGH;
    bool up = digitalRead(BTN_UP), down = digitalRead(BTN_DOWN), center = digitalRead(BTN_CENTER);

    // UP/DOWN adjust selected field when not running and not finished
    if (!timerRunning && !timerFinished) {
      if (upPrev == HIGH && up == LOW) {
        if (timerSelectField == 0) timerSetMinutes = min(59, timerSetMinutes + 1);
        else timerSetSeconds = min(59, timerSetSeconds + 1);
        timerDurationMillis = (unsigned long)timerSetMinutes * 60000UL + (unsigned long)timerSetSeconds * 1000UL;
        timerSavePrefs();
      }
      if (downPrev == HIGH && down == LOW) {
        if (timerSelectField == 0) timerSetMinutes = max(0, timerSetMinutes - 1);
        else timerSetSeconds = max(0, timerSetSeconds - 1);
        timerDurationMillis = (unsigned long)timerSetMinutes * 60000UL + (unsigned long)timerSetSeconds * 1000UL;
        timerSavePrefs();
      }
    }

    // CENTER: short press toggles start/pause; long press (>=1000ms) stops & exit; while setting, center cycles field on quick release
    static unsigned long centerDownAt = 0;
    if (centerPrev == HIGH && center == LOW) centerDownAt = now;

    if (centerPrev == LOW && center == HIGH) {
      unsigned long held = now - centerDownAt;
      if (held < 1000) { // short
        if (!timerFinished) {
          if (!timerRunning) {
            // start: set the start time reference and keep timerDurationMillis as total duration
            timerRunning = true;
            timerStartMillis = millis();
          } else {
            // pause: compute remaining duration and store it in timerDurationMillis
            unsigned long elapsed = millis() - timerStartMillis;
            if (elapsed < timerDurationMillis) timerDurationMillis -= elapsed;
            else timerDurationMillis = 0;
            timerRunning = false;
          }
        } else {
          // finished: stop buzzer, clear done, exit timer
          timerFinished = false;
          timerMode = false;
          digitalWrite(BUZZER_PIN, LOW);
          myDisplay.clear();
        }
      } else { // long press -> reset & exit
        timerRunning = false;
        timerFinished = false;
        timerMode = false;
        // reload saved values
        prefs.begin("watchprefs", false);
        timerSetMinutes = prefs.getInt("timerMin", 0);
        timerSetSeconds = prefs.getInt("timerSec", 30);
        prefs.end();
        timerDurationMillis = (unsigned long)timerSetMinutes * 60000UL + (unsigned long)timerSetSeconds * 1000UL;
        myDisplay.clear();
      }
    }

    // cycle selected field on short tap of center while not running (we detect quick tap by checking rising edge and held < 300ms)
    // To avoid interfering with start, we instead detect a quick press-release where we didn't start the timer.
    static unsigned long lastCenterReleased = 0;
    if (centerPrev == LOW && center == HIGH) {
      unsigned long held = now - centerDownAt;
      if (held < 300 && !timerRunning && !timerFinished) {
        // cycle field
        timerSelectField = (timerSelectField + 1) % 2;
      }
      lastCenterReleased = now;
    }

    upPrev = up;
    downPrev = down;
    centerPrev = center;
    if (up == LOW || down == LOW || center == LOW) lastInteraction = now;
    return;
  }

  // Non-timer path: keep original behavior but retain timer check earlier
  if (stopwatchMode) {
    if (digitalRead(BTN_UP) == LOW || digitalRead(BTN_DOWN) == LOW) lastInteraction = now;
    return;
  }

  static bool upPrev = HIGH, downPrev = HIGH, centerPrev = HIGH;
  bool up = digitalRead(BTN_UP), down = digitalRead(BTN_DOWN), center = digitalRead(BTN_CENTER);
  if (centerPrev == HIGH && center == LOW) { pressStartTime = now; longPressTriggered = false; }
  if (centerPrev == LOW && center == LOW && (now - pressStartTime) > holdTime && !longPressTriggered && !inMenu) {
    inMenu = true; menuIndex = 0; longPressTriggered = true; justEnteredMenu = true; myDisplay.clear(); delay(200);
  }
  if (centerPrev == LOW && center == HIGH) {
    if (justEnteredMenu) justEnteredMenu = false;
    else if (brightnessSettingMode) brightnessSettingMode = false, inMenu = false;
    else if (inMenu && !longPressTriggered) { selectMenu(); showSplashNext = true; }
  }
  if (brightnessSettingMode) {
    if (upPrev == HIGH && up == LOW && currentBrightness < 15) myDisplay.setBrightness(++currentBrightness);
    if (downPrev == HIGH && down == LOW && currentBrightness > 0) myDisplay.setBrightness(--currentBrightness);
  } else if (inMenu) {
    if (upPrev == HIGH && up == LOW) menuIndex = (menuIndex - 1 + totalMenus) % totalMenus;
    if (downPrev == HIGH && down == LOW) menuIndex = (menuIndex + 1) % totalMenus;
  }
  upPrev = up; downPrev = down; centerPrev = center;
  if (up == LOW || down == LOW || center == LOW) lastInteraction = now;
}

// -------------------------
// Menu
// -------------------------
void showMenu() {
  const char *menus[11] = {"Date","Steps","Bright","GPS","RGB","StopWtch","Alarm","Temp","Battery","Timer","Back"};
  if (brightnessSettingMode) { char buf[9]; snprintf(buf, 9, "BR:%02d", currentBrightness); printDisplay(buf); }
  else printDisplay(menus[menuIndex]);
}
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

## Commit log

2025-12-28 Create Cad
2025-12-28 Rename SOL.jpg to PCB View1.jpg
2025-12-28 Rename SOL1.jpg to PCB View1jpg
2025-12-28 Rename PCB View1jpg to PCB View2.jpg

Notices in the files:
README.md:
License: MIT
